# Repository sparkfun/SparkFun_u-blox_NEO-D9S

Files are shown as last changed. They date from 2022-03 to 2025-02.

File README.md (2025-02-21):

SparkFun GNSS Correction Data Receiver - NEO-D9S (Qwiic)
========================================

SparkFun GNSS Correction Data Receiver - NEO-D9S (Qwiic) (https://www.sparkfun.com/products/19390)

[*SparkFun GNSS Correction Data Receiver - NEO-D9S (Qwiic) (GPS-19390)*](https://www.sparkfun.com/products/19390)

The SparkFun NEO-D9S GNSS Correction Data Receiver is a satellite data receiver for L-Band correction broadcast. It can be configured for use with a variety of correction services including u-blox's PointPerfect satellite GNSS augmentation service, which provides homogenous coverage in the contiguous USA. With a clear view of the sky, especially a clear view to the South, it decodes the satellite transmission and outputs a correction stream, enabling a multi-band high-precision GNSS receiver (such as the u-blox ZED-F9P) to reach accuracies down to centimeter-level positioning without needing a separate RTK or NTRIP correction!

The board is equipped with a USB-C connector so you can hook the board to your laptop and configure the device using u-blox u-center if you want to. We've also equipped the breakout board with two Qwiic connectors, so you can connect it quickly and easily to your favorite development board and control it using our sophisticated u-blox GNSS Arduino Library. An SMA connector is included for a secure connection to an L-Band antenna. Power, I<sup>2</sup>C, UART1, UART2, and SPI are broken out to 0.1" spaced PTH pins. By connecting the NEO-D9S breakout to one of the ZED-F9P's communication ports, you will be able to know where your (or any object's) X, Y, and Z location is to better than an inch, without needing a separate correction source!

Repository Contents
-------------------
* **/Documents** - Data sheets, additional product information
* **/Hardware** - Eagle design files (.brd, .sch)

Documentation
--------------
* **[Library](https://github.com/sparkfun/SparkFun_u-blox_GNSS_Arduino_Library)** - Arduino library for the NEO-D9S.
  * **[NEO-D9S Code Example](https://github.com/sparkfun/SparkFun_u-blox_GNSS_Arduino_Library/blob/main/examples/Example30_NEO-D9S/Example30_NEO-D9S.ino)**
  * **[NEO-D9S + ZED-F9P Code Example](https://github.com/sparkfun/SparkFun_u-blox_GNSS_Arduino_Library/tree/main/examples/ZED-F9P/Example19_LBand_Corrections_with_NEO-D9S)**
* **[Hookup Guide](https://learn.sparkfun.com/tutorials/2352)** - Basic hookup guide for the NEO-D9S breakout board.

Product Versions
----------------
* [GPS-19390](https://www.sparkfun.com/products/19390) - Initial release

Version History
---------------
* v1.0 - Initial release

License Information
-------------------

This product is _**open source**_! 

Please review the LICENSE.md file for license information. 

If you have any questions or concerns on licensing, please contact technical support on our [SparkFun forums](https://forum.sparkfun.com/viewforum.php?f=152).

Distributed as-is; no warranty is given.

- Your friends at SparkFun.

_<COLLABORATION CREDIT>_

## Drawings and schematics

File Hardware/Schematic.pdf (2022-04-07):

# Design by: USB⁻C

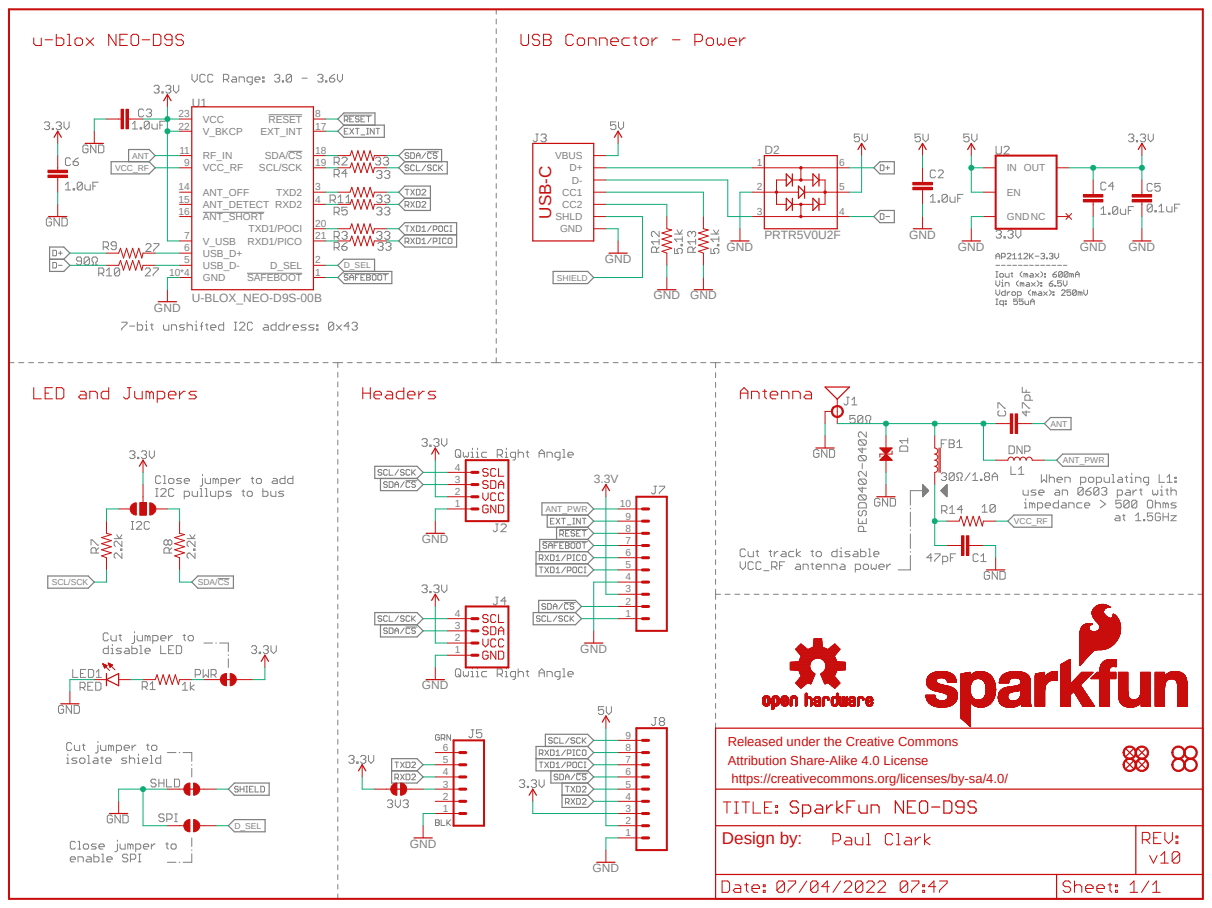
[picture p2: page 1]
GND; PRTR5V0U2F; U-BLOX_NEO-D9S-00B; OUT; VBUS; CC2 SHLD; GND 10*4; VCC 23; RESET 8; EXT_INT 17; SDA/CS 18 SCL/SCK 19; TXD1/POCI 20 RXD1/PICO 21; ANT_OFF 14; V_BKCP 22; RF_IN 11 VCC_RF 9; V_USB 7 USB_D+ 6; USB_D- 5; D_SEL 2; SAFEBOOT 1; TXD2 3 RXD2 4 ANT_DETECT 15; ANT_SHORT 16 U1; SCL/SCK; ANT; D_SEL; VCC_RF; SHIELD; SDA/CS; ANT_PWR

Released under the Creative Commons
Attribution Share-Alike 4.0 License
https://creativecommons.org/licenses/by-sa/4.0/

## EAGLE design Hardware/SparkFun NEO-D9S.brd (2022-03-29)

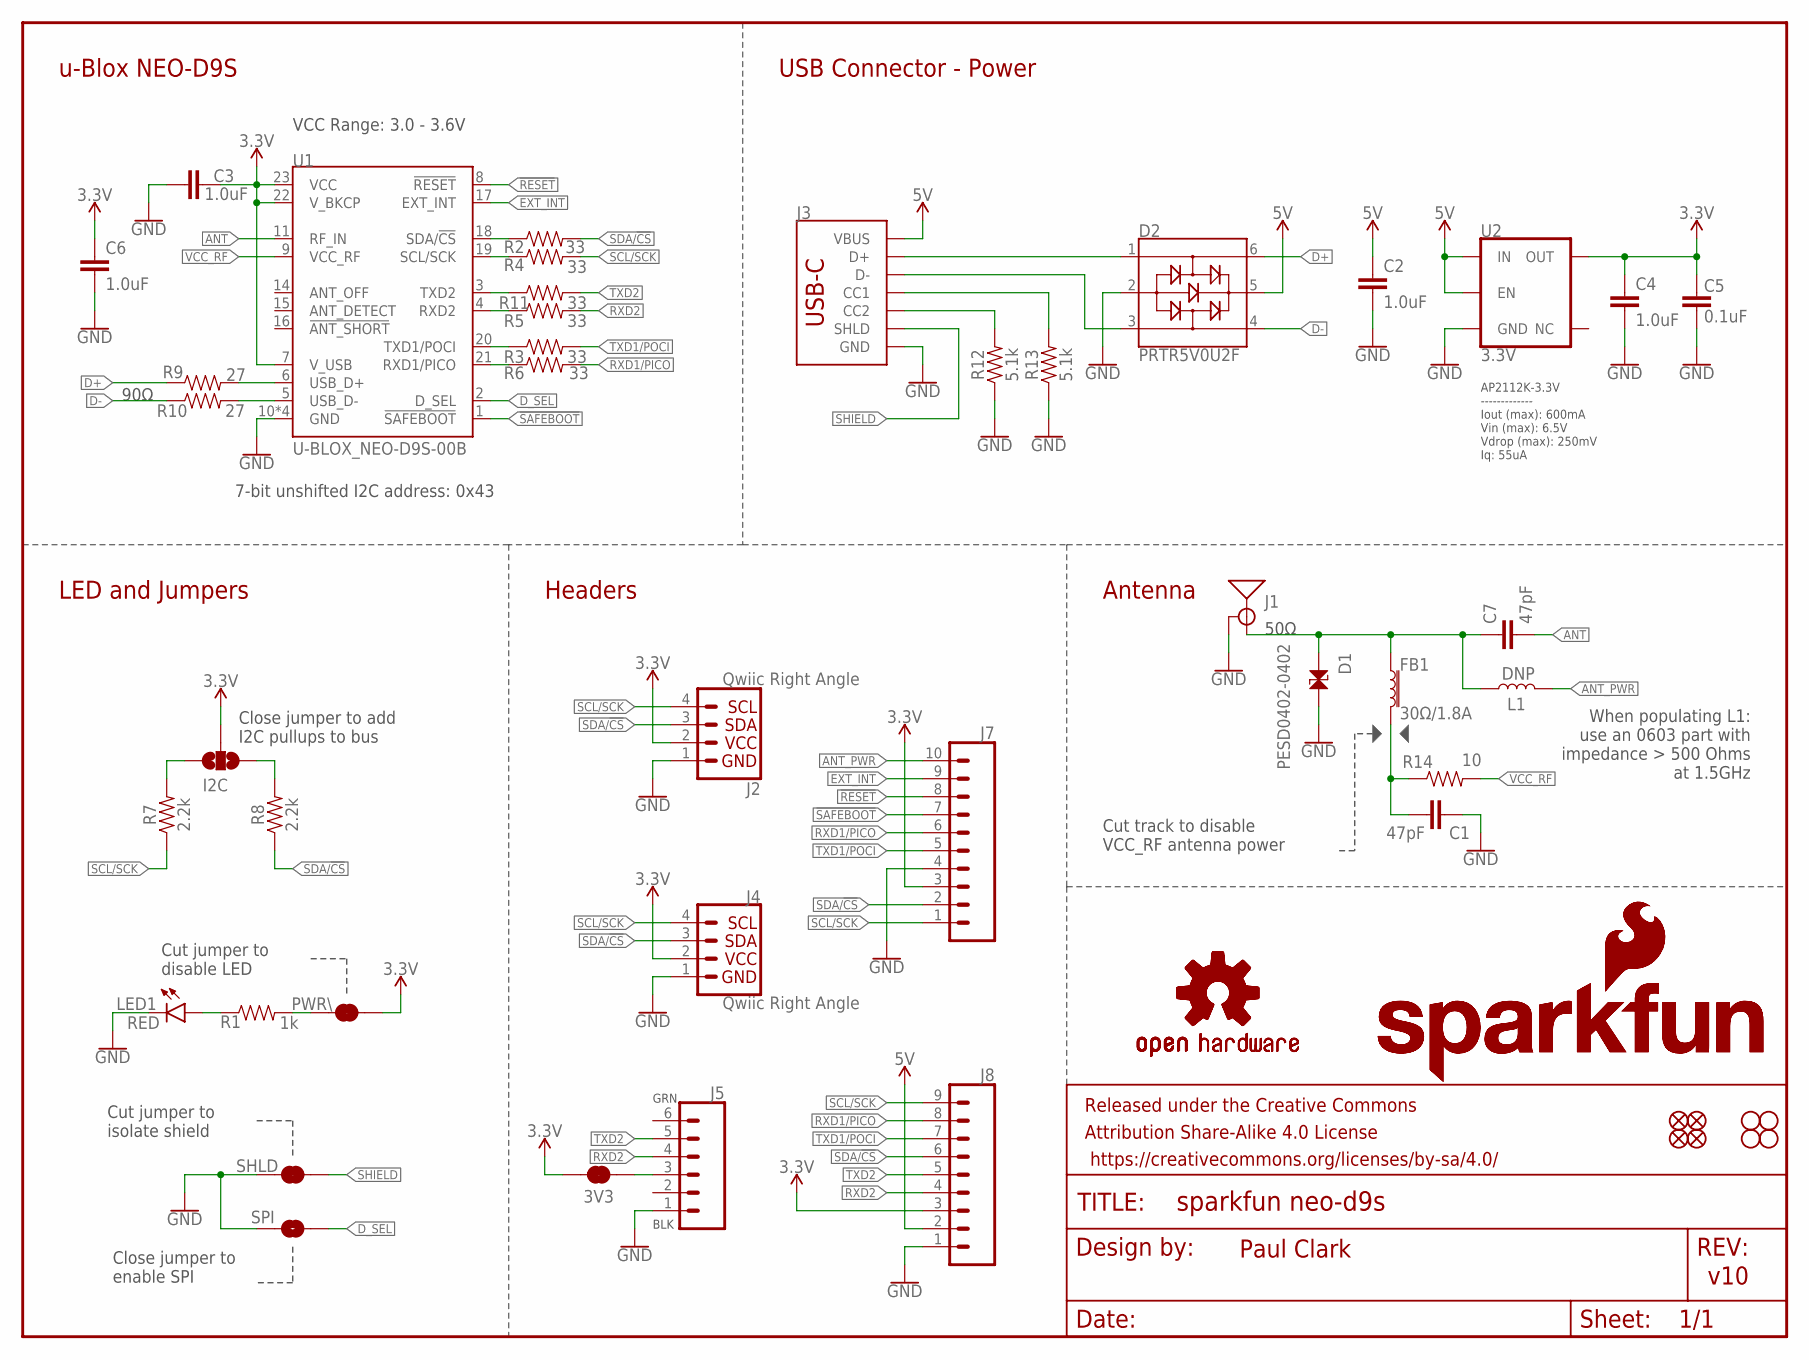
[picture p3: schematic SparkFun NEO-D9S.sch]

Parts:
3V3: JUMPER-SMT_2_NC_TRACE_SILK; SMT-JUMPER_2_NC_TRACE_SILK
C1, C7: 47pF; 0603
C2, C3, C4, C6: 1.0uF; 0603
C5: 0.1uF; 0603
D1: PESD0402-0402; 0402
D2: PRTR5V0U2F; SOT886
FB1: 30Ω/1.8A; 0603
FRAME1: FRAME-LETTER; CREATIVE_COMMONS
I2C: JUMPER-SMT_3_NO_SILK; SMT-JUMPER_3_NO_SILK
J1: ANTENNA-SMA-GROUNDEDEDGE_SMA; SMA-EDGE
J2, J4: Qwiic Right Angle; JST04_1MM_RA
J3: USB_C_2-LAYER_PADS; USB-C-16P-2LAYER-PADS
J5: CONN_06NO_SILK_FEMALE_PTH; 1X06_NO_SILK
J7: CONN_10NO_SILK_PTH_FEMALE; 1X10_NO_SILK
J8: CONN_09NO_SILK; 1X09_NO_SILK
JP21, JP61, JP71, JP81: FIDUCIALUFIDUCIAL; MICRO-FIDUCIAL
JP31, JP41, JP91, JP101: STAND-OFF
L1: DNP; 0603_NO-CREAM
LED1: RED; LED-0603
LOGO1, LOGO4: OSHW-LOGOS; OSHW-LOGO-S
LOGO2, LOGO3: SFE_LOGO_NAME_FLAME.1_INCH; SFE_LOGO_NAME_FLAME_.1
PWR\: JUMPER-SMT_2_NC_TRACE_SILK; SMT-JUMPER_2_NC_TRACE_SILK
R1: 1k; 0603
R2, R3, R4, R5, R6, R11: 33; 0603
R7, R8: 2.2k; 0603
R9, R10: 27; 0603
R12, R13: 5.1k; 0603
R14: 10; 0603
SHLD: JUMPER-SMT_2_NC_TRACE_SILK; SMT-JUMPER_2_NC_TRACE_SILK
SPI: JUMPER-SMT_2_NO_SILK; SMT-JUMPER_2_NO_SILK
U1: U-BLOX_NEO-D9S-00B; NEO-M9N/M8T/M8U/D9S
U2: 3.3V; SOT23-5

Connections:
3.3V: 3V3.2, C3.1, C4.1, C5.2, C6.1, I2C.2, J2.2, J4.2, J7.3, J8.3, PWR\.2, U1.7 (V_USB), U1.22 (V_BKCP), U1.23 (VCC), U2.5 (OUT)
5V: C2.1, D2.5, J3.VBUS1 (VBUS), J3.VBUS2 (VBUS), J8.2, U2.1 (IN), U2.3 (EN)
!RESET!: J7.8, U1.8 (!RESET!)
!SAFEBOOT!: J7.7, U1.1 (!SAFEBOOT!)
ANT: C7.2, U1.11 (RF_IN)
ANT_PWR: J7.10, L1.2
ANT_VCC: C1.1, FB1.2, R14.1
D+: D2.6, R9.1
D-: D2.4, R10.1
D_SEL: SPI.2, U1.2 (D_SEL)
EXT_INT: J7.9, U1.17 (EXT_INT)
GND: C1.2, C2.2, C3.2, C4.2, C5.1, C6.2, D1.2, D2.2, J1.GND@0 (GND), J1.GND@1 (GND), J1.GND@2 (GND), J1.GND@3 (GND), J2.1, J3.GND, J3.GND2 (GND), J4.1, J5.1, J7.4, J8.1, LED1.C, R12.1, R13.1, SHLD.1, SPI.1, U1.10 (GND), U1.12 (GND), U1.13 (GND), U1.24 (GND), U2.2 (GND)
unnamed: PWR\.1, R1.2
unnamed: R3.1, U1.20 (TXD1/POCI)
unnamed: R2.1, U1.18 (SDA/!CS!)
unnamed: R4.1, U1.19 (SCL/SCK)
unnamed: I2C.1, R8.2
unnamed: R6.1, U1.21 (RXD1/PICO)
unnamed: J3.B5 (CC2), R12.2
unnamed: I2C.3, R7.2
unnamed: J3.A5 (CC1), R13.2
unnamed: LED1.A, R1.1
unnamed: R9.2, U1.6 (USB_D+)
unnamed: R10.2, U1.5 (USB_D-)
unnamed: 3V3.1, J5.3
unnamed: R11.1, U1.3 (TXD2)
unnamed: R5.1, U1.4 (RXD2)
RXD1/PICO: J7.6, J8.8, R6.2
RXD2: J5.4, J8.4, R5.2
SCL/SCK: J2.4, J4.4, J7.1, J8.9, R4.2, R7.1
SDA/!CS!: J2.3, J4.3, J7.2, J8.6, R2.2, R8.1
SHIELD: J3.SHLD1 (SHLD), J3.SHLD2 (SHLD), J3.SHLD3 (SHLD), J3.SHLD4 (SHLD), SHLD.2
SMA: C7.1, D1.1, FB1.1, J1.SIG (SIGNAL), L1.1
TXD1/POCI: J7.5, J8.7, R3.2
TXD2: J5.5, J8.5, R11.2
USB_D+: D2.1, J3.A6 (D+), J3.B6 (D+)
USB_D-: D2.3, J3.A7 (D-), J3.B7 (D-)
VCC_RF: R14.2, U1.9 (VCC_RF)

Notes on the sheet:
v10
7-bit unshifted I2C address: 0x43
Close jumper to add I2C pullups to bus
Cut jumper to disable LED
Close jumper to enable SPI
Paul Clark
Headers
LED and Jumpers
u-Blox NEO-D9S
Antenna
USB Connector - Power
VCC Range: 3.0 - 3.6V
BLK
GRN
Cut jumper to isolate shield
50Ω
Cut track to disable VCC_RF antenna power
90Ω
When populating L1: use an 0603 part with impedance > 500 Ohms at 1.5GHz
AP2112K-3.3V ------------- Iout (max): 600mA Vin (max): 6.5V Vdrop (max): 250mV Iq: 55uA

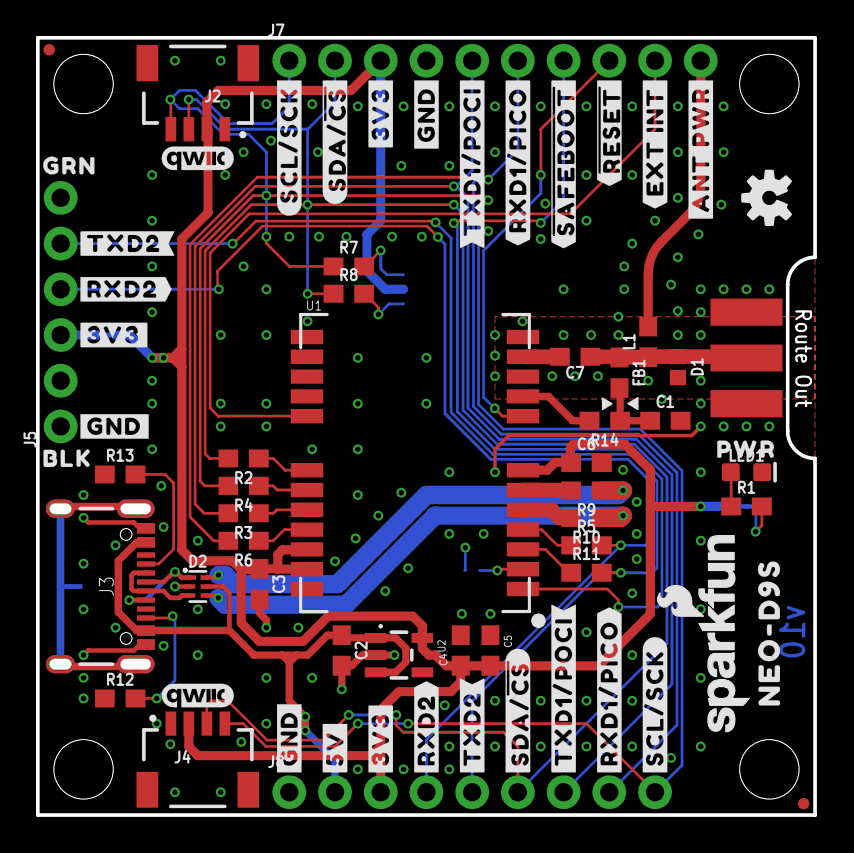
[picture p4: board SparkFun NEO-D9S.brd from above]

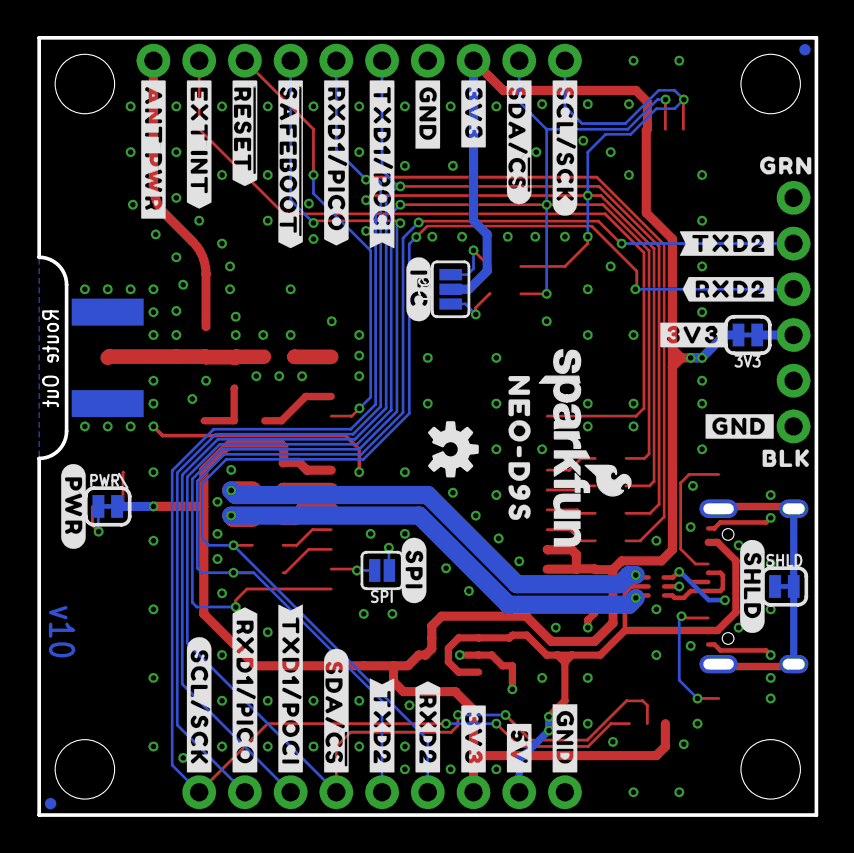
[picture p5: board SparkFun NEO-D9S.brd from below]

Board: 2 copper layers, 43.2 x 43.2 mm, 112 parts (39 on the bottom side), 38 nets.

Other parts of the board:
U$1, U$2, U$3: #GND#0
U$4, U$5, U$6: #GND#1
U$7, U$8: #TXD2#0
U$9, U$10: #TXD2#3
U$11, U$12: #RXD2#0
U$13, U$15: #RXD2#3
U$14, U$38: QWIIC_4MM
U$16, U$17: BLK0
U$18, U$19: GRN0
U$20: #5V#0
U$21: #5V#6
U$22, U$23, U$56, U$57: #3V3#0
U$24, U$25: #3V3#4
U$26, U$27: #SDA##CS##0
U$28, U$29: #SDA##CS##1
U$30, U$31: #TXD1#POCI#0
U$32, U$33: #TXD1#POCI#2
U$34, U$35: #RXD1#PICO#0
U$36, U$37: #RXD1#PICO#2
U$39, U$40: #SCL#SCK#0
U$41, U$42: #SCL#SCK#1
U$43: ##SAFEBOOT##0
U$44: ##SAFEBOOT##1
U$45: ##RESET##0
U$46: ##RESET##1
U$47: #EXT_INT#0
U$48: #EXT_INT#1
U$49: PWR0
U$50: #PWR#0
U$51: #SPI#0
U$52: #I�C#0
U$53: #SHLD#0
U$54, U$55: NEO#D9S0
U$58: #ANT_PWR#0
U$59: #ANT_PWR#1

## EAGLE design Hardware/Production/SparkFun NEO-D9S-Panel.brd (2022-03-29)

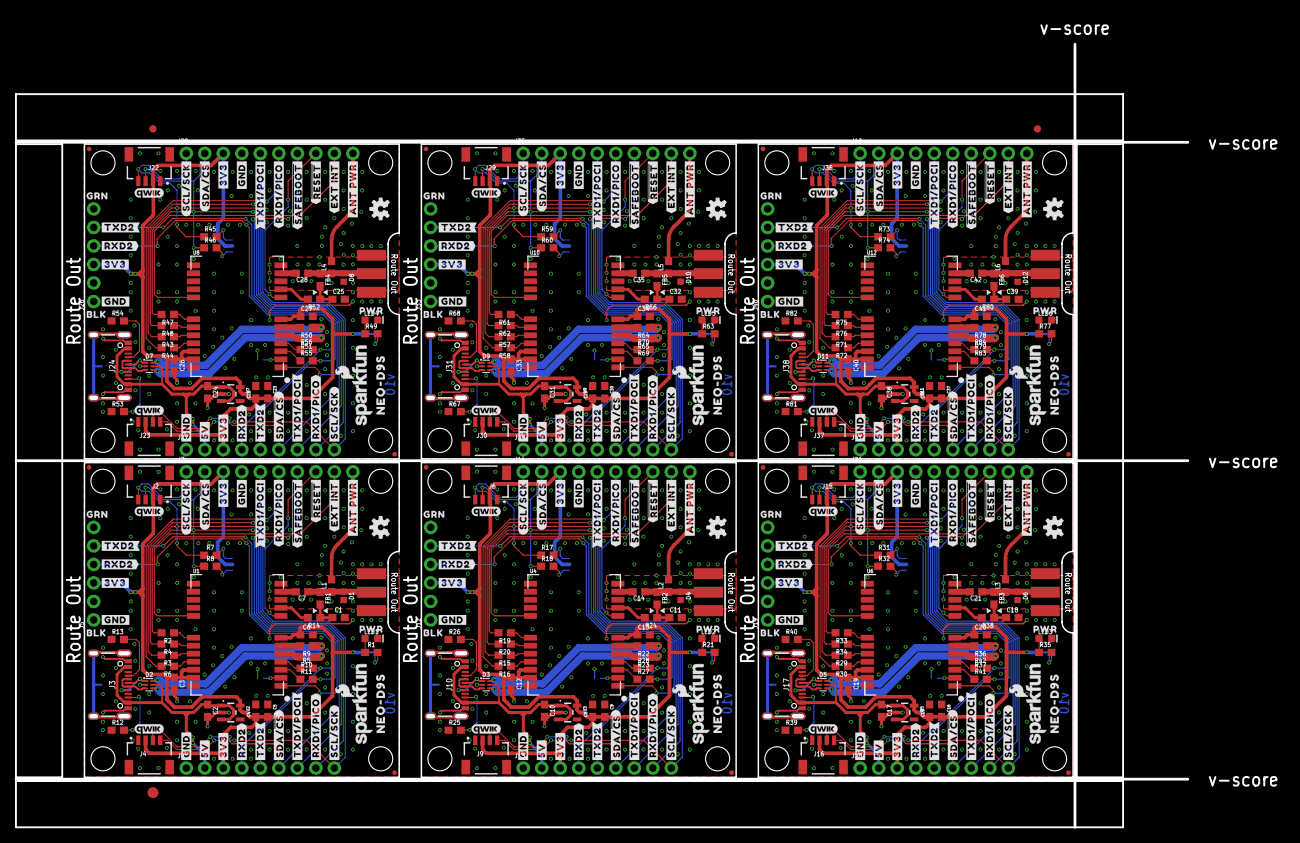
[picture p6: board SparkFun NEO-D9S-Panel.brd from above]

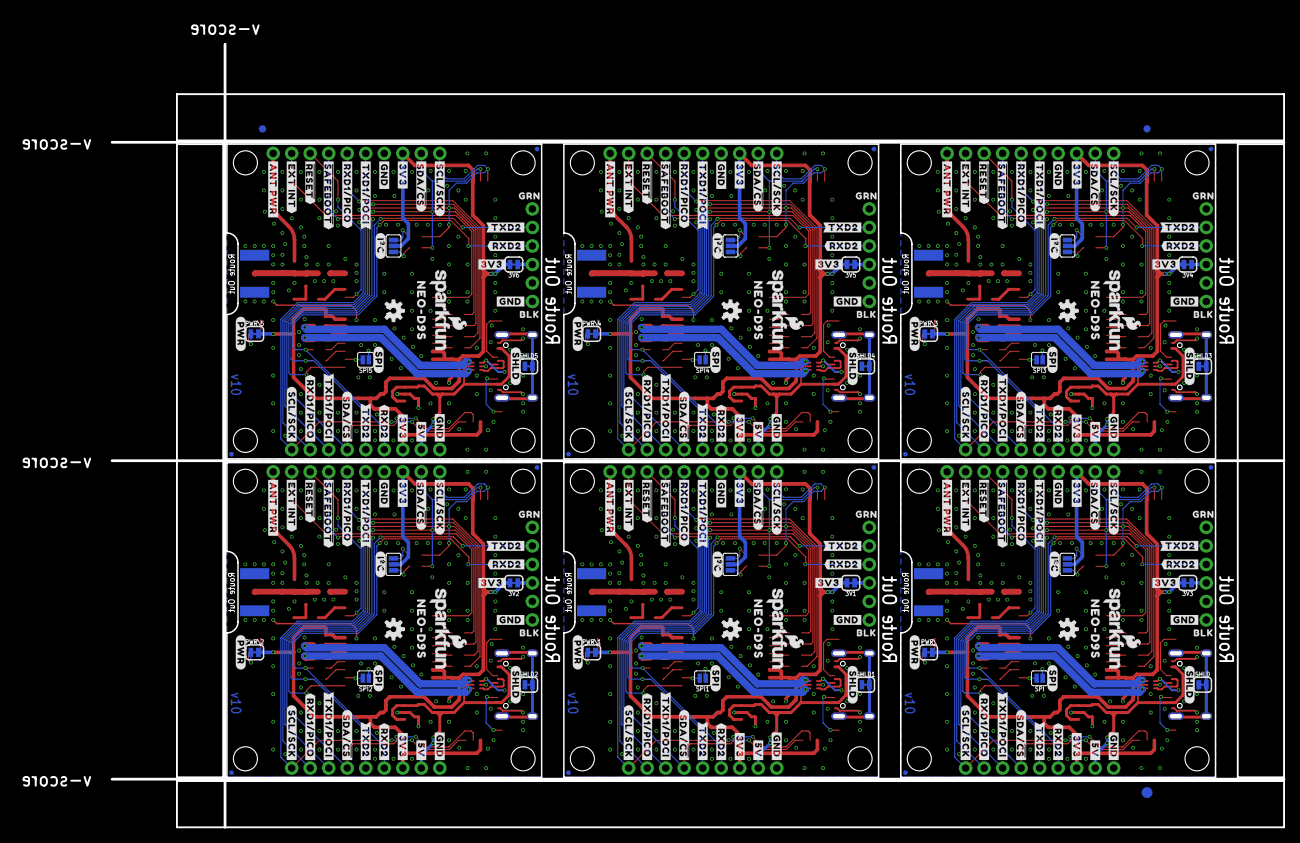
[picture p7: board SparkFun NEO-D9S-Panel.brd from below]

Board: 2 copper layers, 160.8 x 107.4 mm, 672 parts (237 on the bottom side), 228 nets.

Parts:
3V1, 3V2, 3V3, 3V4, 3V5, 3V6: JUMPER-SMT_2_NC_TRACE_SILK; SMT-JUMPER_2_NC_TRACE_SILK
C1, C7, C11, C14, C18, C21, C25, C28, C32, C35, C39, C42: 47pF; 0603
C2, C3, C4, C6, C8, C10, C12, C13, C15, C17, C19, C20, C22, C24, C26, C27, C29, C31, C33, C34, C36, C38, C40, C41: 1.0uF; 0603
C5, C9, C16, C23, C30, C37: 0.1uF; 0603
D1, D4, D6, D8, D10, D12: PESD0402-0402; 0402
D2, D3, D5, D7, D9, D11: PRTR5V0U2F; SOT886
E$1, E$2, E$3, E$4: FIDUCIAL-1X2
E$5, E$6: FIDUCIAL-1.5X3
FB1, FB2, FB3, FB4, FB5, FB6: 30Ω/1.8A; 0603
I2C, I2C1, I2C2, I2C3, I2C4, I2C5: JUMPER-SMT_3_NO_SILK; SMT-JUMPER_3_NO_SILK
J1, J11, J18, J25, J32, J39: ANTENNA-SMA-GROUNDEDEDGE_SMA; SMA-EDGE
J2, J4, J6, J9, J15, J16, J22, J23, J29, J30, J36, J37: Qwiic Right Angle; JST04_1MM_RA
J3, J10, J17, J24, J31, J38: USB-C-16P-2LAYER-PADS
J5, J12, J19, J26, J33, J40: 1X06_NO_SILK
J7, J14, J21, J28, J35, J42: 1X10_NO_SILK
J8, J13, J20, J27, J34, J41: 1X09_NO_SILK
JP1, JP2, JP7, JP8, JP9, JP10, JP15, JP16, JP17, JP18, JP24, JP25, JP26, JP27, JP31, JP33, JP34, JP35, JP36, JP41, JP42, JP43, JP91, JP101: STAND-OFF
JP3, JP4, JP5, JP6, JP11, JP12, JP13, JP14, JP19, JP20, JP21, JP22, JP23, JP28, JP29, JP30, JP32, JP37, JP38, JP39, JP40, JP61, JP71, JP81: FIDUCIALUFIDUCIAL; MICRO-FIDUCIAL
L1, L2, L3, L4, L5, L6: DNP; 0603_NO-CREAM
LED1, LED2, LED3, LED4, LED5, LED6: RED; LED-0603
LOGO1, LOGO4, LOGO5, LOGO8, LOGO9, LOGO12, LOGO13, LOGO16, LOGO17, LOGO20, LOGO21, LOGO24: OSHW-LOGOS; OSHW-LOGO-S
LOGO2, LOGO3, LOGO6, LOGO7, LOGO10, LOGO11, LOGO14, LOGO15, LOGO18, LOGO19, LOGO22, LOGO23: SFE_LOGO_NAME_FLAME.1_INCH; SFE_LOGO_NAME_FLAME_.1
PWR\, PWR\1, PWR\2, PWR\3, PWR\4, PWR\5: JUMPER-SMT_2_NC_TRACE_SILK; SMT-JUMPER_2_NC_TRACE_SILK
R1, R21, R35, R49, R63, R77: 1k; 0603
R2, R3, R4, R5, R6, R11, R15, R16, R19, R20, R27, R28, R29, R30, R33, R34, R41, R42, R43, R44, R47, R48, R55, R56, R57, R58, R61, R62, R69, R70, R71, R72, R75, R76, R83, R84: 33; 0603
R7, R8, R17, R18, R31, R32, R45, R46, R59, R60, R73, R74: 2.2k; 0603
R9, R10, R22, R23, R36, R37, R50, R51, R64, R65, R78, R79: 27; 0603
R12, R13, R25, R26, R39, R40, R53, R54, R67, R68, R81, R82: 5.1k; 0603
R14, R24, R38, R52, R66, R80: 10; 0603
SHLD, SHLD1, SHLD2, SHLD3, SHLD4, SHLD5: JUMPER-SMT_2_NC_TRACE_SILK; SMT-JUMPER_2_NC_TRACE_SILK
SPI, SPI1, SPI2, SPI3, SPI4, SPI5: JUMPER-SMT_2_NO_SILK; SMT-JUMPER_2_NO_SILK
U1, U4, U6, U8, U10, U12: U-BLOX_NEO-D9S-00B; NEO-M9N/M8T/M8U/D9S
U2, U3, U5, U7, U9, U11: 3.3V; SOT23-5
U$1, U$2, U$3, U$61, U$62, U$63, U$120, U$121, U$122, U$179, U$180, U$181, U$238, U$239, U$240, U$297, U$298, U$299: #GND#0
U$4, U$5, U$6, U$64, U$65, U$66, U$123, U$124, U$125, U$182, U$183, U$184, U$241, U$242, U$243, U$300, U$301, U$302: #GND#1
U$7, U$8, U$67, U$68, U$126, U$127, U$185, U$186, U$244, U$245, U$303, U$304: #TXD2#0
U$9, U$10, U$69, U$70, U$128, U$129, U$187, U$188, U$246, U$247, U$305, U$306: #TXD2#3
U$11, U$12, U$71, U$72, U$130, U$131, U$189, U$190, U$248, U$249, U$307, U$308: #RXD2#0
U$13, U$15, U$73, U$74, U$132, U$133, U$191, U$192, U$250, U$251, U$309, U$310: #RXD2#3
U$14, U$38, U$60, U$114, U$119, U$173, U$178, U$232, U$237, U$291, U$296, U$350: QWIIC_4MM
U$16, U$17, U$75, U$76, U$134, U$135, U$193, U$194, U$252, U$253, U$311, U$312: BLK0
U$18, U$19, U$77, U$78, U$136, U$137, U$195, U$196, U$254, U$255, U$313, U$314: GRN0
U$20, U$79, U$138, U$197, U$256, U$315: #5V#0
U$21, U$80, U$139, U$198, U$257, U$316: #5V#6
U$22, U$23, U$56, U$57, U$81, U$82, U$115, U$116, U$140, U$141, U$174, U$175, U$199, U$200, U$233, U$234, U$258, U$259, U$292, U$293, U$317, U$318, U$351, U$352: #3V3#0
U$24, U$25, U$83, U$84, U$142, U$143, U$201, U$202, U$260, U$261, U$319, U$320: #3V3#4
U$26, U$27, U$85, U$86, U$144, U$145, U$203, U$204, U$262, U$263, U$321, U$322: #SDA##CS##0
U$28, U$29, U$87, U$88, U$146, U$147, U$205, U$206, U$264, U$265, U$323, U$324: #SDA##CS##1
U$30, U$31, U$106, U$107, U$165, U$166, U$224, U$225, U$283, U$284, U$342, U$343: #TXD1#POCI#0
U$32, U$33, U$108, U$109, U$167, U$168, U$226, U$227, U$285, U$286, U$344, U$345: #TXD1#POCI#2
U$34, U$35, U$110, U$111, U$169, U$170, U$228, U$229, U$287, U$288, U$346, U$347: #RXD1#PICO#0
U$36, U$37, U$112, U$113, U$171, U$172, U$230, U$231, U$289, U$290, U$348, U$349: #RXD1#PICO#2
U$39, U$40, U$89, U$90, U$148, U$149, U$207, U$208, U$266, U$267, U$325, U$326: #SCL#SCK#0
U$41, U$42, U$91, U$92, U$150, U$151, U$209, U$210, U$268, U$269, U$327, U$328: #SCL#SCK#1
U$43, U$93, U$152, U$211, U$270, U$329: ##SAFEBOOT##0
U$44, U$94, U$153, U$212, U$271, U$330: ##SAFEBOOT##1
U$45, U$95, U$154, U$213, U$272, U$331: ##RESET##0
U$46, U$96, U$155, U$214, U$273, U$332: ##RESET##1
U$47, U$97, U$156, U$215, U$274, U$333: #EXT_INT#0
U$48, U$98, U$157, U$216, U$275, U$334: #EXT_INT#1
U$49, U$99, U$158, U$217, U$276, U$335: PWR0
U$50, U$100, U$159, U$218, U$277, U$336: #PWR#0
U$51, U$101, U$160, U$219, U$278, U$337: #SPI#0
U$52, U$102, U$161, U$220, U$279, U$338: #I�C#0
U$53, U$103, U$162, U$221, U$280, U$339: #SHLD#0
U$54, U$55, U$104, U$105, U$163, U$164, U$222, U$223, U$281, U$282, U$340, U$341: NEO#D9S0
U$58, U$117, U$176, U$235, U$294, U$353: #ANT_PWR#0
U$59, U$118, U$177, U$236, U$295, U$354: #ANT_PWR#1

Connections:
3.3V: 3V3.2, C3.1, C4.1, C5.2, C6.1, I2C.2, J2.2, J4.2, J7.3, J8.3, PWR\.2, U1.7, U1.22, U1.23, U2.5
3.3V1: 3V1.2, C8.1, C9.2, C12.1, C13.1, I2C1.2, J6.2, J9.2, J13.3, J14.3, PWR\1.2, U3.5, U4.7, U4.22, U4.23
3.3V2: 3V2.2, C15.1, C16.2, C19.1, C20.1, I2C2.2, J15.2, J16.2, J20.3, J21.3, PWR\2.2, U5.5, U6.7, U6.22, U6.23
3.3V3: 3V4.2, C22.1, C23.2, C26.1, C27.1, I2C3.2, J22.2, J23.2, J27.3, J28.3, PWR\3.2, U7.5, U8.7, U8.22, U8.23
3.3V4: 3V5.2, C29.1, C30.2, C33.1, C34.1, I2C4.2, J29.2, J30.2, J34.3, J35.3, PWR\4.2, U9.5, U10.7, U10.22, U10.23
3.3V5: 3V6.2, C36.1, C37.2, C40.1, C41.1, I2C5.2, J36.2, J37.2, J41.3, J42.3, PWR\5.2, U11.5, U12.7, U12.22, U12.23
5V: C2.1, D2.5, J3.VBUS1, J3.VBUS2, J8.2, U2.1, U2.3
5V1: C10.1, D3.5, J10.VBUS1, J10.VBUS2, J13.2, U3.1, U3.3
5V2: C17.1, D5.5, J17.VBUS1, J17.VBUS2, J20.2, U5.1, U5.3
5V3: C24.1, D7.5, J24.VBUS1, J24.VBUS2, J27.2, U7.1, U7.3
5V4: C31.1, D9.5, J31.VBUS1, J31.VBUS2, J34.2, U9.1, U9.3
5V5: C38.1, D11.5, J38.VBUS1, J38.VBUS2, J41.2, U11.1, U11.3
!RESET!: J7.8, U1.8
!RESET!1: J14.8, U4.8
!RESET!2: J21.8, U6.8
!RESET!3: J28.8, U8.8
!RESET!4: J35.8, U10.8
!RESET!5: J42.8, U12.8
!SAFEBOOT!: J7.7, U1.1
!SAFEBOOT!1: J14.7, U4.1
!SAFEBOOT!2: J21.7, U6.1
!SAFEBOOT!3: J28.7, U8.1
!SAFEBOOT!4: J35.7, U10.1
!SAFEBOOT!5: J42.7, U12.1
ANT: C7.2, U1.11
ANT1: C14.2, U4.11
ANT2: C21.2, U6.11
ANT3: C28.2, U8.11
ANT4: C35.2, U10.11
ANT5: C42.2, U12.11
ANT_PWR: J7.10, L1.2
ANT_PWR1: J14.10, L2.2
ANT_PWR2: J21.10, L3.2
ANT_PWR3: J28.10, L4.2
ANT_PWR4: J35.10, L5.2
ANT_PWR5: J42.10, L6.2
ANT_VCC: C1.1, FB1.2, R14.1
ANT_VCC1: C11.1, FB2.2, R24.1
ANT_VCC2: C18.1, FB3.2, R38.1
ANT_VCC3: C25.1, FB4.2, R52.1
ANT_VCC4: C32.1, FB5.2, R66.1
ANT_VCC5: C39.1, FB6.2, R80.1
D+: D2.6, R9.1
D+1: D3.6, R22.1
D+2: D5.6, R36.1
D+3: D7.6, R50.1
D+4: D9.6, R64.1
D+5: D11.6, R78.1
D-: D2.4, R10.1
D-1: D3.4, R23.1
D-2: D5.4, R37.1
D-3: D7.4, R51.1
D-4: D9.4, R65.1
D-5: D11.4, R79.1
D_SEL: SPI.2, U1.2
D_SEL1: SPI1.2, U4.2
D_SEL2: SPI2.2, U6.2
D_SEL3: SPI3.2, U8.2
D_SEL4: SPI4.2, U10.2
D_SEL5: SPI5.2, U12.2
EXT_INT: J7.9, U1.17
EXT_INT1: J14.9, U4.17
EXT_INT2: J21.9, U6.17
EXT_INT3: J28.9, U8.17
EXT_INT4: J35.9, U10.17
EXT_INT5: J42.9, U12.17
GND: C1.2, C2.2, C3.2, C4.2, C5.1, C6.2, D1.2, D2.2, J1.GND@0, J1.GND@1, J1.GND@2, J1.GND@3, J2.1, J3.GND, J3.GND2, J4.1, J5.1, J7.4, J8.1, LED1.C, R12.1, R13.1, SHLD.1, SPI.1, U1.10, U1.12, U1.13, U1.24, U2.2
GND1: C8.2, C9.1, C10.2, C11.2, C12.2, C13.2, D3.2, D4.2, J6.1, J9.1, J10.GND, J10.GND2, J11.GND@0, J11.GND@1, J11.GND@2, J11.GND@3, J12.1, J13.1, J14.4, LED2.C, R25.1, R26.1, SHLD1.1, SPI1.1, U3.2, U4.10, U4.12, U4.13, U4.24
GND2: C15.2, C16.1, C17.2, C18.2, C19.2, C20.2, D5.2, D6.2, J15.1, J16.1, J17.GND, J17.GND2, J18.GND@0, J18.GND@1, J18.GND@2, J18.GND@3, J19.1, J20.1, J21.4, LED3.C, R39.1, R40.1, SHLD2.1, SPI2.1, U5.2, U6.10, U6.12, U6.13, U6.24
GND3: C22.2, C23.1, C24.2, C25.2, C26.2, C27.2, D7.2, D8.2, J22.1, J23.1, J24.GND, J24.GND2, J25.GND@0, J25.GND@1, J25.GND@2, J25.GND@3, J26.1, J27.1, J28.4, LED4.C, R53.1, R54.1, SHLD3.1, SPI3.1, U7.2, U8.10, U8.12, U8.13, U8.24
GND4: C29.2, C30.1, C31.2, C32.2, C33.2, C34.2, D9.2, D10.2, J29.1, J30.1, J31.GND, J31.GND2, J32.GND@0, J32.GND@1, J32.GND@2, J32.GND@3, J33.1, J34.1, J35.4, LED5.C, R67.1, R68.1, SHLD4.1, SPI4.1, U9.2, U10.10, U10.12, U10.13, U10.24
GND5: C36.2, C37.1, C38.2, C39.2, C40.2, C41.2, D11.2, D12.2, J36.1, J37.1, J38.GND, J38.GND2, J39.GND@0, J39.GND@1, J39.GND@2, J39.GND@3, J40.1, J41.1, J42.4, LED6.C, R81.1, R82.1, SHLD5.1, SPI5.1, U11.2, U12.10, U12.12, U12.13, U12.24
unnamed: PWR\.1, R1.2
unnamed: R3.1, U1.20
unnamed: R2.1, U1.18
unnamed: R4.1, U1.19
unnamed: I2C.1, R8.2
unnamed: R6.1, U1.21
unnamed: J3.B5, R12.2
unnamed: I2C.3, R7.2
unnamed: J3.A5, R13.2
unnamed: LED1.A, R1.1
unnamed: R9.2, U1.6
unnamed: R10.2, U1.5
unnamed: 3V3.1, J5.3
unnamed: R11.1, U1.3
unnamed: R5.1, U1.4
unnamed: I2C1.1, R18.2
unnamed: I2C1.3, R17.2
unnamed: LED2.A, R21.1
unnamed: R22.2, U4.6
unnamed: R23.2, U4.5
unnamed: PWR\1.1, R21.2
unnamed: J10.B5, R25.2
unnamed: J10.A5, R26.2
unnamed: R27.1, U4.3
unnamed: R28.1, U4.4
unnamed: R15.1, U4.20
unnamed: R16.1, U4.21
unnamed: R19.1, U4.18
unnamed: R20.1, U4.19
unnamed: 3V1.1, J12.3
unnamed: I2C2.1, R32.2
unnamed: I2C2.3, R31.2
unnamed: LED3.A, R35.1
unnamed: R36.2, U6.6
unnamed: R37.2, U6.5
unnamed: PWR\2.1, R35.2
unnamed: J17.B5, R39.2
unnamed: J17.A5, R40.2
unnamed: R41.1, U6.3
unnamed: R42.1, U6.4
unnamed: R29.1, U6.20
unnamed: R30.1, U6.21
unnamed: R33.1, U6.18
unnamed: R34.1, U6.19
unnamed: 3V2.1, J19.3
unnamed: I2C3.1, R46.2
unnamed: I2C3.3, R45.2
unnamed: LED4.A, R49.1
unnamed: R50.2, U8.6
unnamed: R51.2, U8.5
unnamed: PWR\3.1, R49.2
unnamed: J24.B5, R53.2
unnamed: J24.A5, R54.2
unnamed: R55.1, U8.3
unnamed: R56.1, U8.4
unnamed: R43.1, U8.20
unnamed: R44.1, U8.21
unnamed: R47.1, U8.18
unnamed: R48.1, U8.19
unnamed: 3V4.1, J26.3
unnamed: I2C4.1, R60.2
unnamed: I2C4.3, R59.2
unnamed: LED5.A, R63.1
unnamed: R64.2, U10.6
unnamed: R65.2, U10.5
unnamed: PWR\4.1, R63.2
unnamed: J31.B5, R67.2
unnamed: J31.A5, R68.2
unnamed: R69.1, U10.3
unnamed: R70.1, U10.4
unnamed: R57.1, U10.20
unnamed: R58.1, U10.21
unnamed: R61.1, U10.18
unnamed: R62.1, U10.19
unnamed: 3V5.1, J33.3
unnamed: I2C5.1, R74.2
unnamed: I2C5.3, R73.2
unnamed: LED6.A, R77.1
unnamed: R78.2, U12.6
unnamed: R79.2, U12.5
unnamed: PWR\5.1, R77.2
unnamed: J38.B5, R81.2
unnamed: J38.A5, R82.2
unnamed: R83.1, U12.3
unnamed: R84.1, U12.4
unnamed: R71.1, U12.20
unnamed: R72.1, U12.21
unnamed: R75.1, U12.18
unnamed: R76.1, U12.19
unnamed: 3V6.1, J40.3
RXD1: J12.4, J13.4, R28.2
RXD1/PICO: J7.6, J8.8, R6.2
RXD1/PICO1: J13.8, J14.6, R16.2
RXD1/PICO2: J20.8, J21.6, R30.2
RXD1/PICO3: J27.8, J28.6, R44.2
RXD1/PICO4: J34.8, J35.6, R58.2
RXD1/PICO5: J41.8, J42.6, R72.2
RXD2: J5.4, J8.4, R5.2
RXD3: J19.4, J20.4, R42.2
RXD4: J26.4, J27.4, R56.2
RXD5: J33.4, J34.4, R70.2
RXD6: J40.4, J41.4, R84.2
SCL/SCK: J2.4, J4.4, J7.1, J8.9, R4.2, R7.1
SCL/SCK1: J6.4, J9.4, J13.9, J14.1, R17.1, R20.2
SCL/SCK2: J15.4, J16.4, J20.9, J21.1, R31.1, R34.2
SCL/SCK3: J22.4, J23.4, J27.9, J28.1, R45.1, R48.2
SCL/SCK4: J29.4, J30.4, J34.9, J35.1, R59.1, R62.2
SCL/SCK5: J36.4, J37.4, J41.9, J42.1, R73.1, R76.2
SDA/!CS!: J2.3, J4.3, J7.2, J8.6, R2.2, R8.1
SDA/!CS!1: J6.3, J9.3, J13.6, J14.2, R18.1, R19.2
SDA/!CS!2: J15.3, J16.3, J20.6, J21.2, R32.1, R33.2
SDA/!CS!3: J22.3, J23.3, J27.6, J28.2, R46.1, R47.2
SDA/!CS!4: J29.3, J30.3, J34.6, J35.2, R60.1, R61.2
SDA/!CS!5: J36.3, J37.3, J41.6, J42.2, R74.1, R75.2
SHIELD: J3.SHLD1, J3.SHLD2, J3.SHLD3, J3.SHLD4, SHLD.2
SHIELD1: J10.SHLD1, J10.SHLD2, J10.SHLD3, J10.SHLD4, SHLD1.2
SHIELD2: J17.SHLD1, J17.SHLD2, J17.SHLD3, J17.SHLD4, SHLD2.2
SHIELD3: J24.SHLD1, J24.SHLD2, J24.SHLD3, J24.SHLD4, SHLD3.2
SHIELD4: J31.SHLD1, J31.SHLD2, J31.SHLD3, J31.SHLD4, SHLD4.2
SHIELD5: J38.SHLD1, J38.SHLD2, J38.SHLD3, J38.SHLD4, SHLD5.2
SMA: C7.1, D1.1, FB1.1, J1.SIG, L1.1
SMA1: C14.1, D4.1, FB2.1, J11.SIG, L2.1
SMA2: C21.1, D6.1, FB3.1, J18.SIG, L3.1
SMA3: C28.1, D8.1, FB4.1, J25.SIG, L4.1
SMA4: C35.1, D10.1, FB5.1, J32.SIG, L5.1
SMA5: C42.1, D12.1, FB6.1, J39.SIG, L6.1
TXD1: J12.5, J13.5, R27.2
TXD1/POCI: J7.5, J8.7, R3.2
TXD1/POCI1: J13.7, J14.5, R15.2
TXD1/POCI2: J20.7, J21.5, R29.2
TXD1/POCI3: J27.7, J28.5, R43.2
TXD1/POCI4: J34.7, J35.5, R57.2
TXD1/POCI5: J41.7, J42.5, R71.2
TXD2: J5.5, J8.5, R11.2
TXD3: J19.5, J20.5, R41.2
TXD4: J26.5, J27.5, R55.2
TXD5: J33.5, J34.5, R69.2
TXD6: J40.5, J41.5, R83.2
USB_D+: D2.1, J3.A6, J3.B6
USB_D+1: D3.1, J10.A6, J10.B6
USB_D+2: D5.1, J17.A6, J17.B6
USB_D+3: D7.1, J24.A6, J24.B6
USB_D+4: D9.1, J31.A6, J31.B6
USB_D+5: D11.1, J38.A6, J38.B6
USB_D-: D2.3, J3.A7, J3.B7
USB_D-1: D3.3, J10.A7, J10.B7
USB_D-2: D5.3, J17.A7, J17.B7
USB_D-3: D7.3, J24.A7, J24.B7
USB_D-4: D9.3, J31.A7, J31.B7
USB_D-5: D11.3, J38.A7, J38.B7
VCC_RF: R14.2, U1.9
VCC_RF1: R24.2, U4.9
VCC_RF2: R38.2, U6.9
VCC_RF3: R52.2, U8.9
VCC_RF4: R66.2, U10.9
VCC_RF5: R80.2, U12.9

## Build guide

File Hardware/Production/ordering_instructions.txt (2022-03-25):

panel size, 155x101mm
PCB thickness, 1.6mm
number of layers, 2
soldermask color, Red
silkscreen color, White
oz copper, 1oz
finish, HASL lead free
stencils, top
pcs per panel, 6
min trace width, 0.1524mm / 0.0060in
min drill size, 0.3000mm / 0.0118in

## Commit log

2022-02-08 Routed. Add schematic
    [SparkFun NEO-D9S.brd, SparkFun NEO-D9S.sch]
2022-02-08 Add C6
    [SparkFun NEO-D9S.brd, SparkFun NEO-D9S.sch]
2022-02-08 Final tweaks. Ready for proto review.
    [SparkFun NEO-D9S.brd]
2022-02-09 Add cut marks for antenna power
    [SparkFun NEO-D9S.brd, SparkFun NEO-D9S.sch]
2022-02-11 Post-Proto Review Changes
    [SparkFun NEO-D9S.brd, SparkFun NEO-D9S.sch]
2022-02-16 Add PROD_ID for NEO-D9S-00B. Add Proto production files
    [SparkFun NEO-D9S.brd, SparkFun NEO-D9S.sch]
2022-03-25 Updates for v10 PCB
    [SparkFun NEO-D9S-Panel.GBL, SparkFun NEO-D9S-Panel.GBO, SparkFun NEO-D9S-Panel.GBP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]
2022-03-29 Updates after REDs Review
    [SparkFun NEO-D9S-Panel.brd, SparkFun NEO-D9S.brd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]
2022-04-07 Update schematic
    [SparkFun NEO-D9S.sch]

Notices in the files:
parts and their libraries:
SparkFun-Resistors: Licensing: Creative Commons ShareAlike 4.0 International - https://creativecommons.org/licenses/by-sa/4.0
